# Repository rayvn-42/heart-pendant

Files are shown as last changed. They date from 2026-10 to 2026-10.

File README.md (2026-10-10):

## Heart Pendant
> A two part PCB, one used as a bracelet that senses heart pulses, and a pendant shaped as a heart that shows them

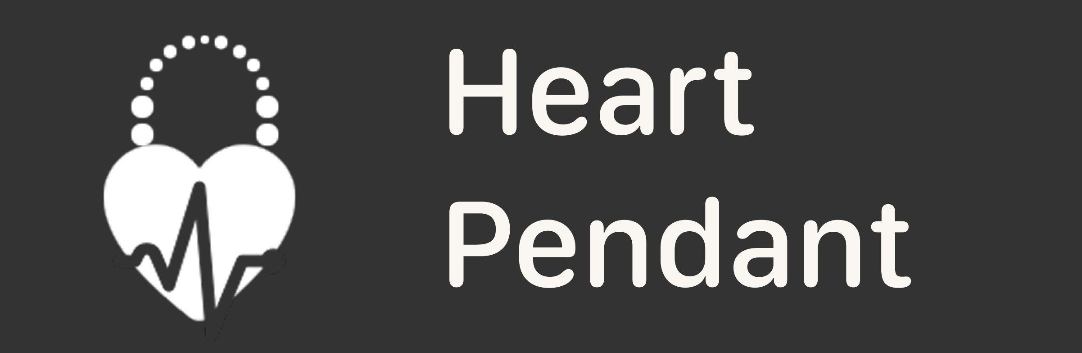
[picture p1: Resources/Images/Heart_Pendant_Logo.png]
Heart Pendant Logo


---

### What is Heart Pendant?
Its a small wearable made of two boards on a single PCB, joined by a break-away joint, The square half is a bracelet that measures the pulse with a heartbeat sensor.The heart-shaped half is a necklace pendant that shows each beat as a light animation moving smoothly around a ring of addressable LEDs. Once you snap the halves apart, each one works on its own and they talk to each other wirelessly.

### Why is Heart Pendant useful?
Its not really useful :), but its just fun and a reminder that each second your heart beats :) or something. I mean its just cool.

---

### How it works?
The bracelet's ESP32-C3 reads a heartbeat sensor module and detects each beat. It sends the beat to the pendant using the ESP-NOW protocol. Then the pendants ESP32 displays that heartbeat as a simple rotational animation using the addressable LEDs. Each half has its own LiPo battery, USB C port with a dedicated charge controller, and a 3v3 regulator, so both can be charged and used separately.

## So far
- [x] Schematic: ESP32 core, USB-C input, charger, regulator, power switch, battery sensing
- [x] Pulse sensor and LED ring
- [x] PCB layout
- [x] Quote Component & PCB + Stencil Order
- [ ] Firmware

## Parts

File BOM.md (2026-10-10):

# Heart pendant – bill of materials

<!-- Generated by Half Life from project cmuuxpitj0bii01smvdh1ma1b. Edits here are overwritten on the next sync. -->
<!-- Generated: 2026-10-10T14:42:43.618Z -->

> [!NOTE]
> This parts list is mirrored from [Half Life](https://halflife.hackclub.com). Editing it here will not change the platform's copy, and the next sync overwrites this file.

| Week | Tier | Parts funding |
| --- | --- | --- |
| Week 1 | Tier 3 | $100.00 |

| Part | What it's for | Qty | Unit | Total | Vendor |
| --- | --- | --- | --- | --- | --- |
| [PCB Components](https://www.lcsc.com/product-detail/C41349510.html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) | All components for the pcb, not indivdually listed since part value too low | 1 | $21.29 | $21.29 | [LCSC](https://www.lcsc.com/product-detail/C41349510.html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) |
| [PCB + Stencil](https://cart.jlcpcb.com/shopcart/cart) | The Board and Stencil | 1 | $16.72 | $16.72 | [JLCPCB](https://cart.jlcpcb.com/shopcart/cart) |
| **Parts subtotal** | — | — | — | **$38.01** | — |
| **Tax & shipping** | — | — | — | **$59.00** | — |
| **Total** | — | — | — | **$97.01** | — |

$2.99 left of the tier's funding.

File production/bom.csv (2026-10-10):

Designator | Footprint | Quantity | Value | LCSC Part #
C1, C24, C28, C7, C8, C9 | 0603 | 6 | 1uF | C1592
C10, C2 | 0805 | 2 | 10uF | C1713
C11, C12, C14, C3, C4, C6 | 0603 | 6 | 4.7uF | C1705
C13, C15, C16, C17, C18, C19, C20, C21, C22, C23, C25, C26, C27, C5 | 0603 | 14 | 100nF | C1590
D1, D2 | 0603 | 2 | LED | C2286
D10, D11, D12, D13, D14, D3, D4, D5, D6, D7, D8, D9 | LED_SK6812MINI-E_3.2x2.8mm_P1.5mm_ReverseMount | 12 | SK6812MINI-E | C5149201
J2, J4 | USB_C_Receptacle_HRO_TYPE-C-31-M-12 | 2 | USB_C_Receptacle_USB2.0_16P | C165948
Q1 | SOT-23 | 1 | 2N7002 | C8545
Q2 | SOT-23 | 1 | AO3401A | C478608
R1, R10, R11, R18, R2 | 0603 | 5 | 100k | C14675
R12, R13, R14, R15, R17, R3, R4, R5, R6 | 0603 | 9 | 10k | C15401
R16, R7 | 0603 | 2 | 470R | C23179
R19 | 0603 | 1 | 330R | C22104
R20, R21, R8, R9 | 0603 | 4 | 5.1k | C14677
SW1, SW3 | SW-SMD_4P-L4.2-W3.4-P2.15-LS5.2 | 2 | SW_Boot | C55200589
SW2, SW4 | SW-TH_MSK12C02 | 2 | SW_SPDT | C431540
U1, U6 | SOT-23-5 | 2 | MCP73831-2-OT | C14879
U2, U7 | WIFIM-SMD_ESP32-C3-MINI-1 | 2 | ESP32-C3-MINI-1-N4X | C41349510
U4, U9 | SOT-23-5 | 2 | AP2112K-3.3 | C51118
U5, U8 | SOT-23-6 | 2 | USBLC6-2SC6 | C7519

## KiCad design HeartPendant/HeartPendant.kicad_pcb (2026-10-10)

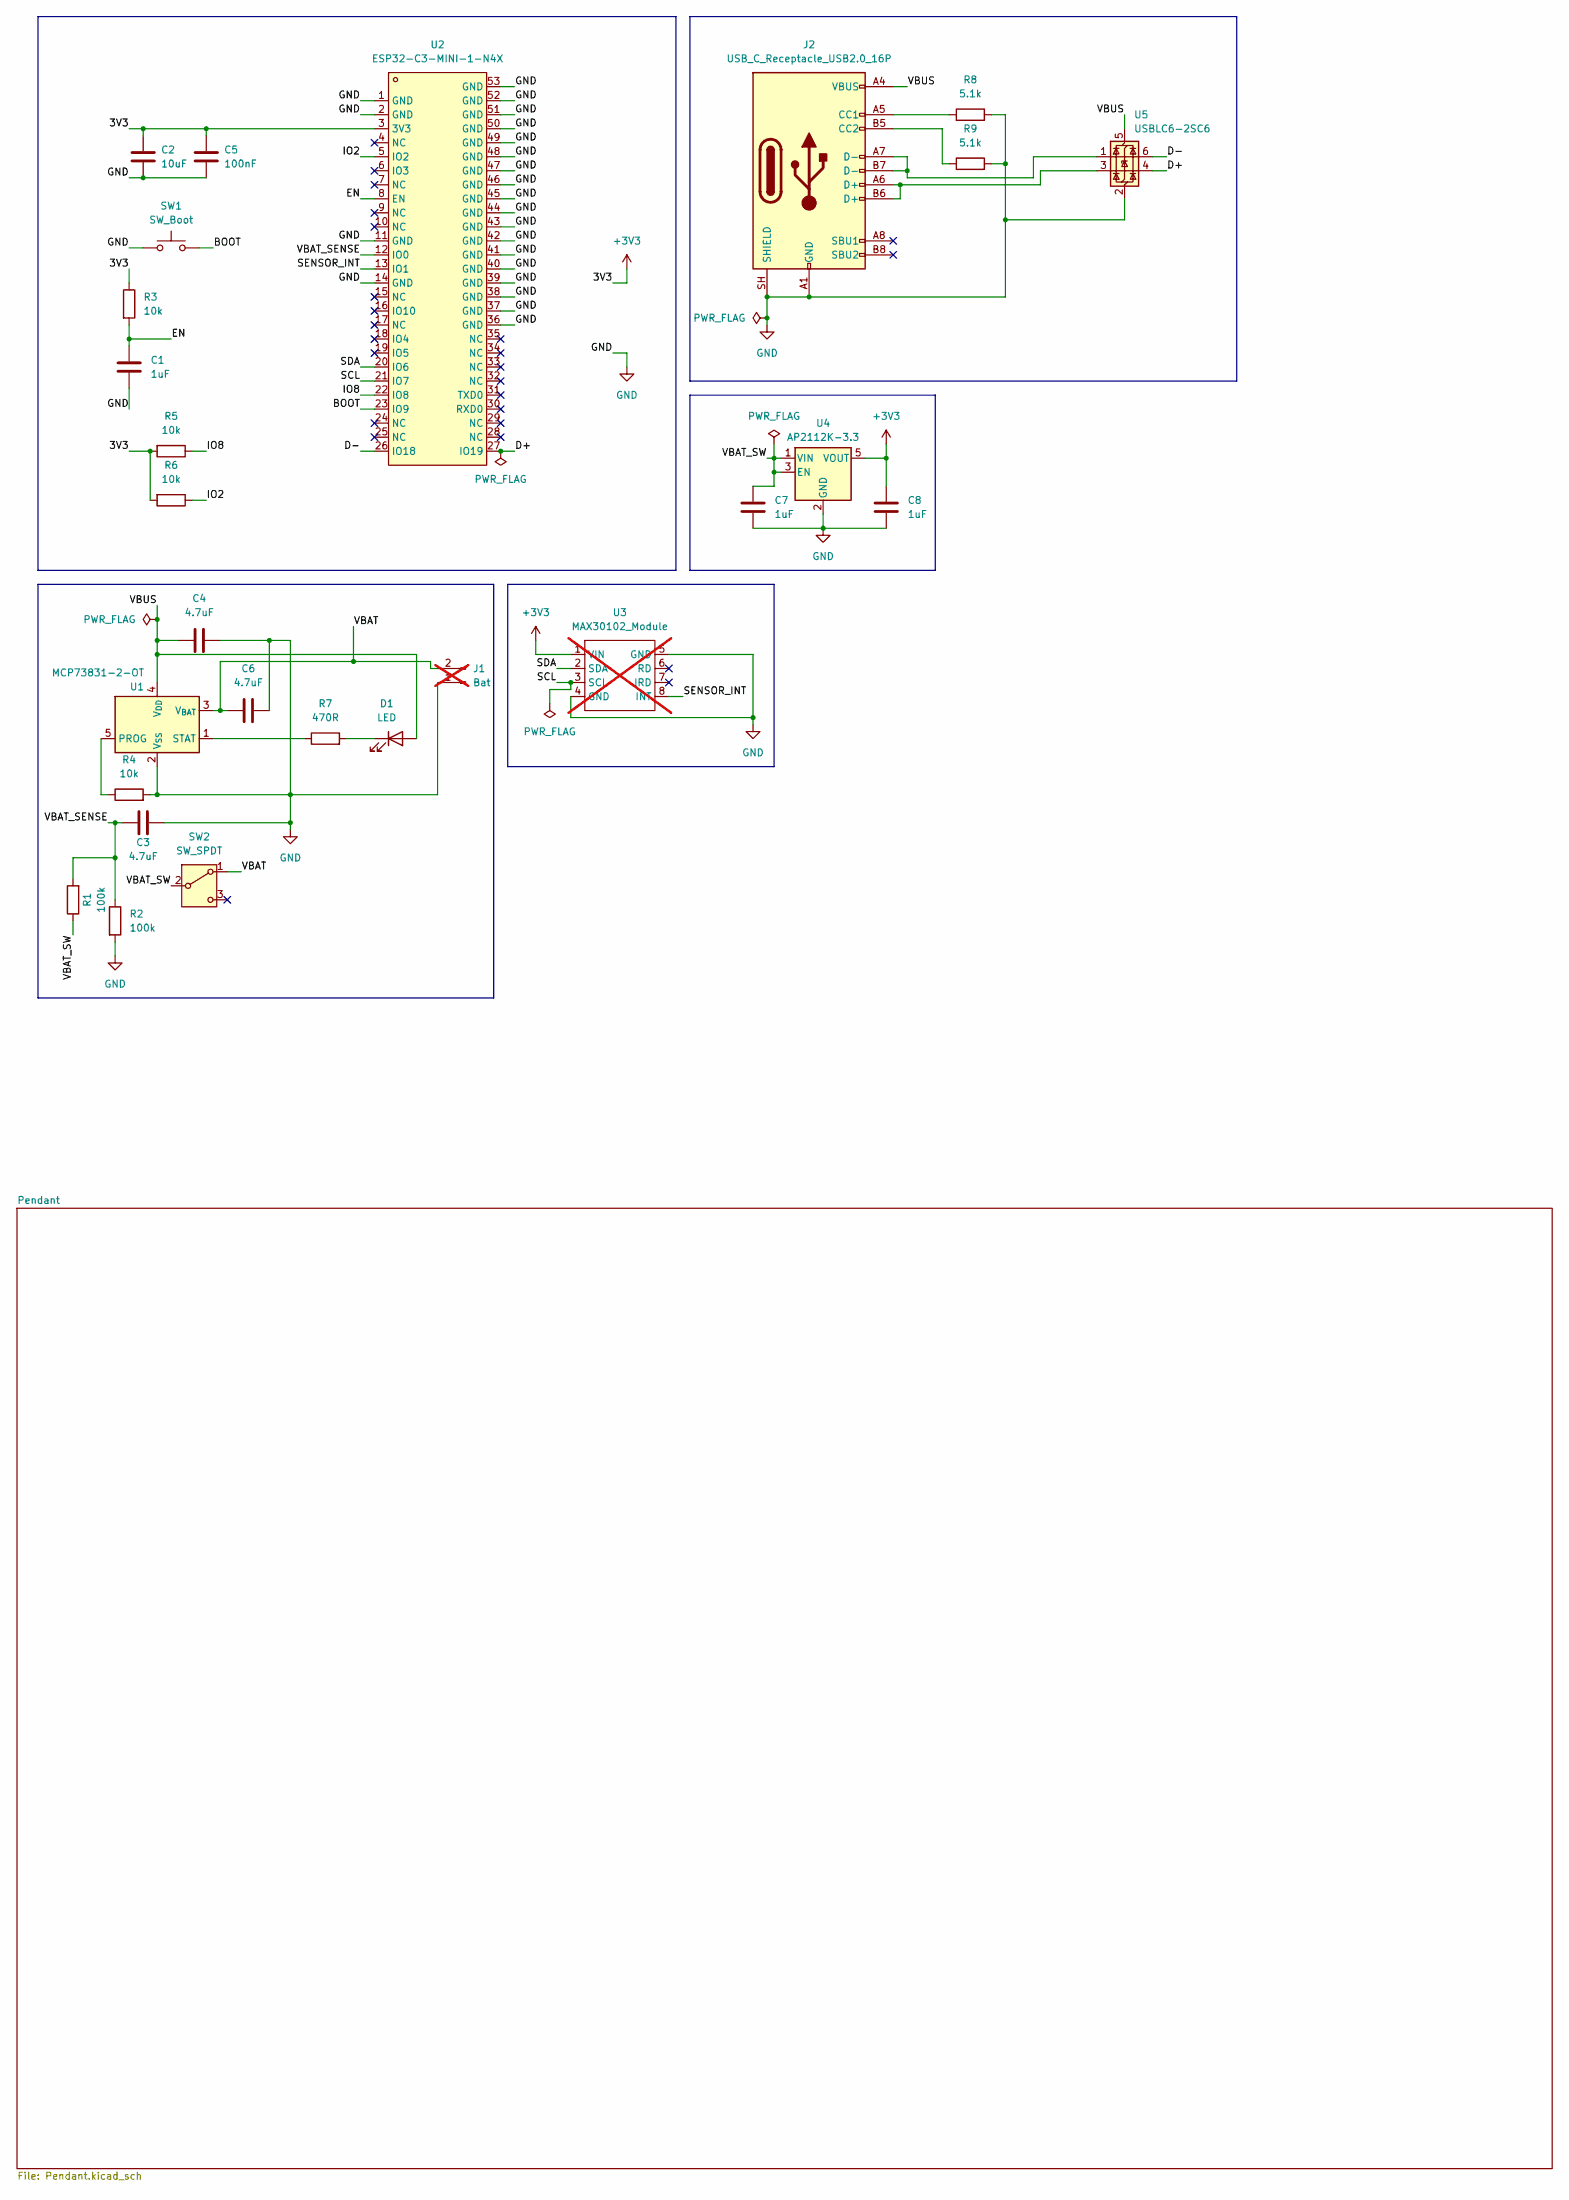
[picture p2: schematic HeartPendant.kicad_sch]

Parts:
C1, C7, C8: 1uF; C_0603_1608Metric; LCSC Part C1592
C2: 10uF; C_0805_2012Metric; LCSC Part C1713
C3, C4, C6: 4.7uF; C_0603_1608Metric; LCSC Part C1705
C5: 100nF; C_0603_1608Metric; LCSC Part C1590
D1: LED; LED_0603_1608Metric; LCSC Part C2286
J1: Bat; PinHeader_1x02_P2.54mm_Vertical; not fitted
J2: USB_C_Receptacle_USB2.0_16P; USB_C_Receptacle_HRO_TYPE-C-31-M-12; LCSC Part C165948
R1, R2: 100k; R_0603_1608Metric; LCSC Part C14675
R3, R4, R5, R6: 10k; R_0603_1608Metric; LCSC Part C15401
R7: 470R; R_0603_1608Metric; LCSC Part C23179
R8, R9: 5.1k; R_0603_1608Metric; LCSC Part C14677
SW1: SW_Boot; SW-SMD_4P-L4.2-W3.4-P2.15-LS5.2; LCSC Part C55200589
SW2: SW_SPDT; SW-TH_MSK12C02; LCSC Part C431540
U1: MCP73831-2-OT; SOT-23-5; LCSC Part C14879
U2: ESP32-C3-MINI-1-N4X; WIFIM-SMD_ESP32-C3-MINI-1; MPN ESP32-C3-MINI-1-N4X; LCSC Part C41349510
U3: MAX30102_Module; Max30102_Module; not fitted
U4: AP2112K-3.3; SOT-23-5; LCSC Part C51118
U5: USBLC6-2SC6; SOT-23-6; LCSC Part C7519

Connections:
+3V3: C2.2, C5.2, C8.1, R3.1, R5.2, R6.2, U2.3 (3V3), U3.1 (VIN), U4.5 (VOUT)
/BOOT: SW1.2, U2.23 (IO9)
/D+: U2.27 (IO19), U5.4 (I/O2)
/D-: U2.26 (IO18), U5.6 (I/O1)
/EN: C1.1, R3.2, U2.8 (EN)
/IO2: R6.1, U2.5 (IO2)
/IO8: R5.1, U2.22 (IO8)
/SCL: U2.21 (IO7), U3.3 (SCL)
/SDA: U2.20 (IO6), U3.2 (SDA)
/SENSOR_INT: U2.13 (IO1), U3.8 (INT)
/VBAT: C6.1, J1.2, SW2.1 (A), U1.3 (V_{BAT})
/VBAT_SENSE: C3.1, R1.2, R2.1, U2.12 (IO0)
/VBAT_SW: C7.1, R1.1, SW2.2 (B), U4.1 (VIN), U4.3 (EN)
/VBUS: C4.1, D1.2 (A), J2.A4 (VBUS), J2.A9 (VBUS), J2.B4 (VBUS), J2.B9 (VBUS), U1.4 (V_{DD}), U5.5 (VBUS)
GND: C1.2, C2.1, C3.2, C4.2, C5.1, C6.2, C7.2, C8.2, J1.1, J2.A1 (GND), J2.A12 (GND), J2.B1 (GND), J2.B12 (GND), J2.SH (SHIELD), R2.2, R4.2, R8.2, R9.2, SW1.1, U1.2 (V_{SS}), U2.1 (GND), U2.2 (GND), U2.11 (GND), U2.14 (GND), U2.36 (GND), U2.37 (GND), U2.38 (GND), U2.39 (GND), U2.40 (GND), U2.41 (GND), U2.42 (GND), U2.43 (GND), U2.44 (GND), U2.45 (GND), U2.46 (GND), U2.47 (GND), U2.48 (GND), U2.49 (GND), U2.50 (GND), U2.51 (GND), U2.52 (GND), U2.53 (GND), U3.4 (GND), U3.5 (GND), U4.2 (GND), U5.2 (GND)
unnamed: D1.1 (K), R7.2
unnamed: J2.A5 (CC1), R8.1
unnamed: J2.B5 (CC2), R9.1
unnamed: J2.A6 (D+), J2.B6 (D+), U5.3 (I/O2)
unnamed: J2.A7 (D-), J2.B7 (D-), U5.1 (I/O1)
unnamed: R4.1, U1.5 (PROG)
unnamed: R7.1, U1.1 (STAT)

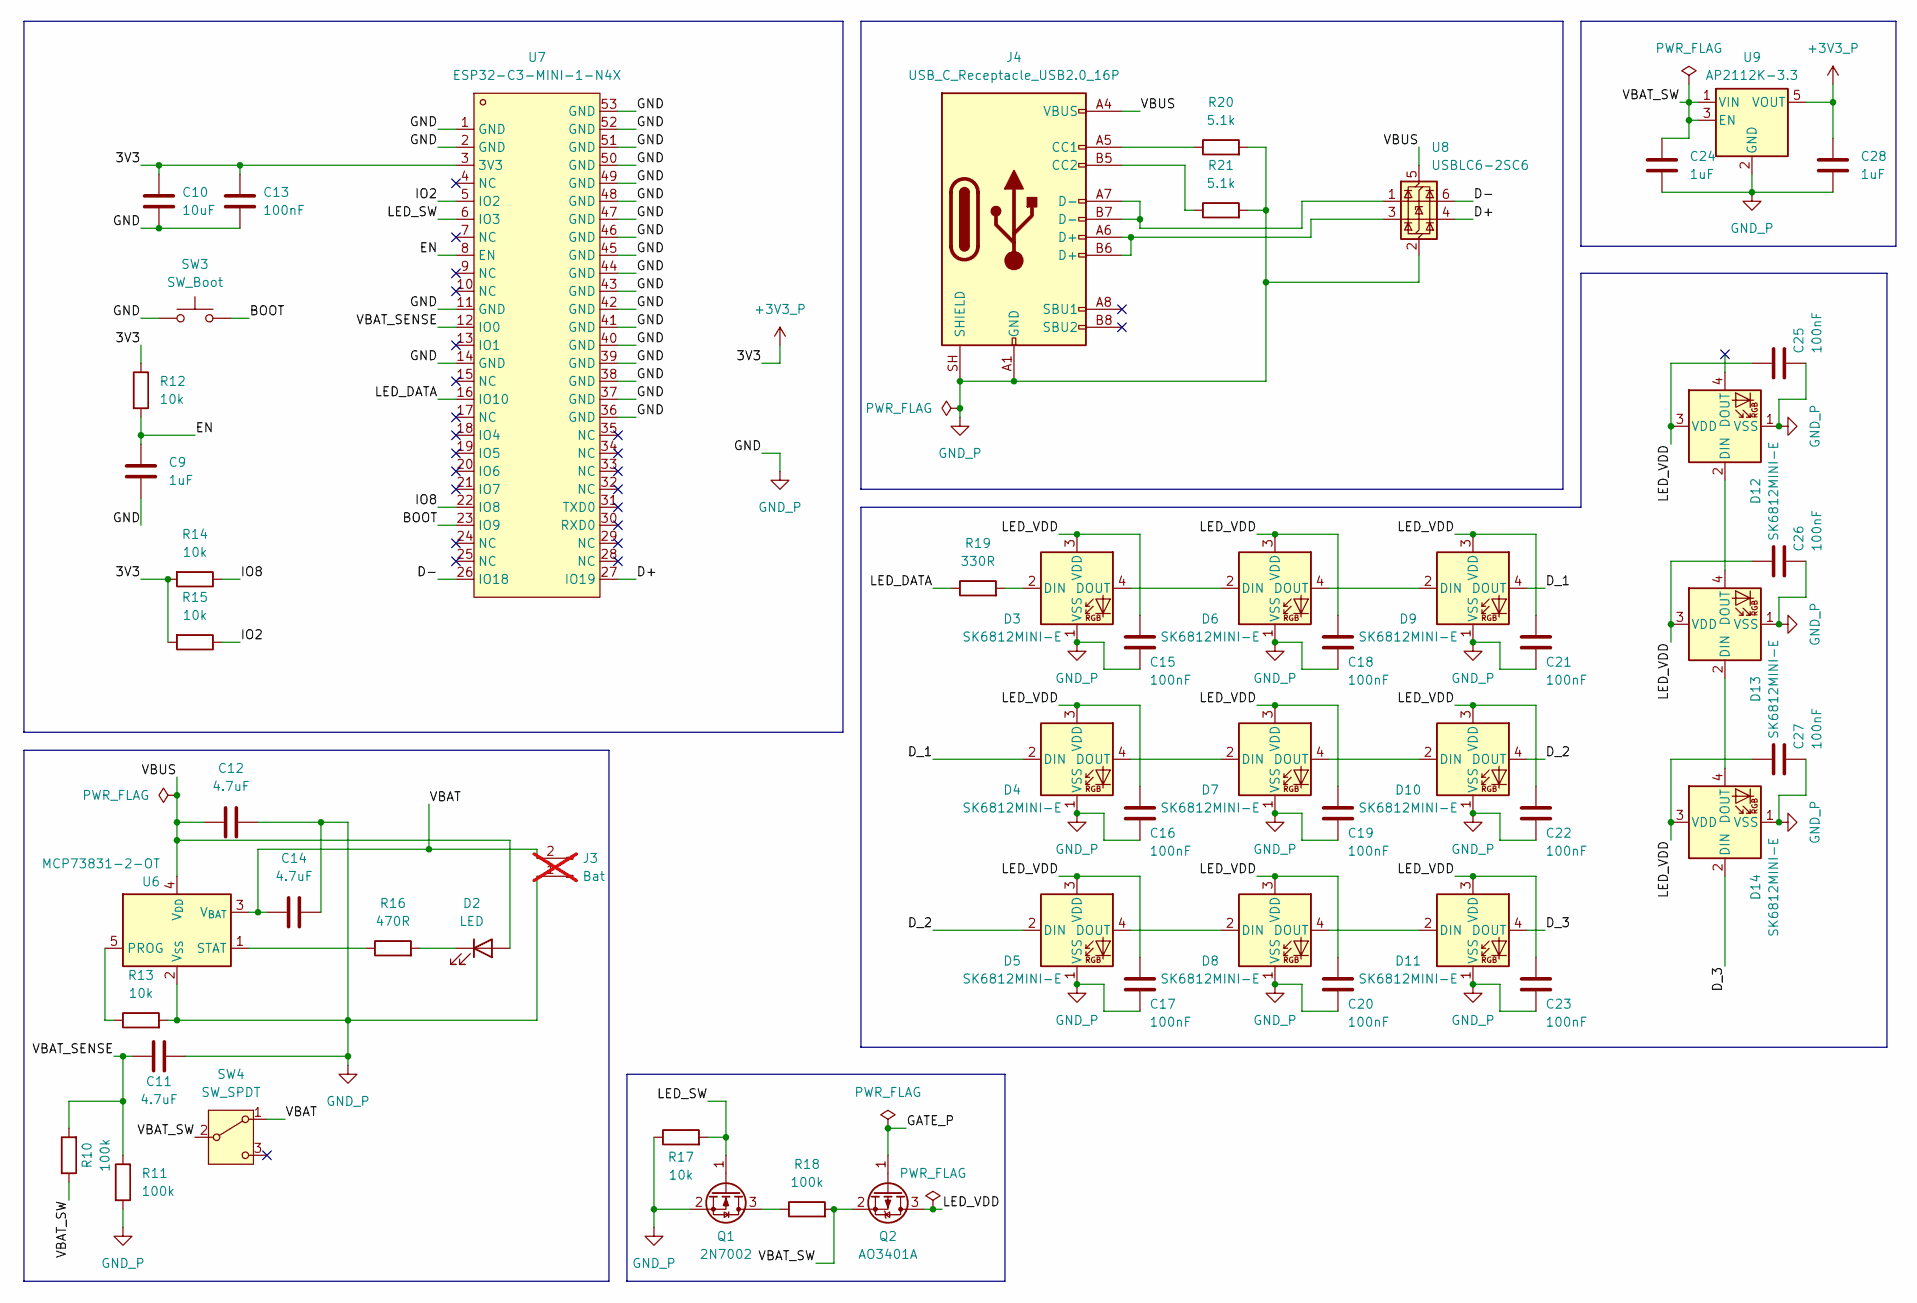
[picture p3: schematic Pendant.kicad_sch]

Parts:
C9, C24, C28: 1uF; C_0603_1608Metric; LCSC Part C1592
C10: 10uF; C_0805_2012Metric; LCSC Part C1713
C11, C12, C14: 4.7uF; C_0603_1608Metric; LCSC Part C1705
C13, C15, C16, C17, C18, C19, C20, C21, C22, C23, C25, C26, C27: 100nF; C_0603_1608Metric; LCSC Part C1590
D2: LED; LED_0603_1608Metric; LCSC Part C2286
D3, D4, D5, D6, D7, D8, D9, D10, D11, D12, D13, D14: SK6812MINI-E; LED_SK6812MINI-E_3.2x2.8mm_P1.5mm_ReverseMount; LCSC Part C5149201
J3: Bat; PinHeader_1x02_P2.54mm_Vertical; not fitted
J4: USB_C_Receptacle_USB2.0_16P; USB_C_Receptacle_HRO_TYPE-C-31-M-12; LCSC Part C165948
Q1: 2N7002; SOT-23; LCSC Part C8545
Q2: AO3401A; SOT-23; LCSC Part C478608
R10, R11, R18: 100k; R_0603_1608Metric; LCSC Part C14675
R12, R13, R14, R15, R17: 10k; R_0603_1608Metric; LCSC Part C15401
R16: 470R; R_0603_1608Metric; LCSC Part C23179
R19: 330R; R_0603_1608Metric; LCSC Part C22104
R20, R21: 5.1k; R_0603_1608Metric; LCSC Part C14677
SW3: SW_Boot; SW-SMD_4P-L4.2-W3.4-P2.15-LS5.2; LCSC Part C55200589
SW4: SW_SPDT; SW-TH_MSK12C02; LCSC Part C431540
U6: MCP73831-2-OT; SOT-23-5; LCSC Part C14879
U7: ESP32-C3-MINI-1-N4X; WIFIM-SMD_ESP32-C3-MINI-1; MPN ESP32-C3-MINI-1-N4X; LCSC Part C41349510
U8: USBLC6-2SC6; SOT-23-6; LCSC Part C7519
U9: AP2112K-3.3; SOT-23-5; LCSC Part C51118

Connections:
+3V3_P: C10.2, C13.2, C28.1, R12.1, R14.2, R15.2, U7.3 (3V3), U9.5 (VOUT)
/Pendant/BOOT: SW3.2, U7.23 (IO9)
/Pendant/D+: U7.27 (IO19), U8.4 (I/O2)
/Pendant/D-: U7.26 (IO18), U8.6 (I/O1)
/Pendant/D_1: D4.2 (DIN), D9.4 (DOUT)
/Pendant/D_2: D5.2 (DIN), D10.4 (DOUT)
/Pendant/D_3: D11.4 (DOUT), D14.2 (DIN)
/Pendant/EN: C9.1, R12.2, U7.8 (EN)
/Pendant/GATE_P: Q2.1 (G)
/Pendant/IO2: R15.1, U7.5 (IO2)
/Pendant/IO8: R14.1, U7.22 (IO8)
/Pendant/LED_DATA: R19.1, U7.16 (IO10)
/Pendant/LED_SW: Q1.1 (G), R17.2, U7.6 (IO3)
/Pendant/LED_VDD: C15.1, C16.1, C17.1, C18.1, C19.1, C20.1, C21.1, C22.1, C23.1, C25.1, C26.1, C27.1, D3.3 (VDD), D4.3 (VDD), D5.3 (VDD), D6.3 (VDD), D7.3 (VDD), D8.3 (VDD), D9.3 (VDD), D10.3 (VDD), D11.3 (VDD), D12.3 (VDD), D13.3 (VDD), D14.3 (VDD), Q2.3 (D)
/Pendant/VBAT: C14.1, J3.2, SW4.1 (A), U6.3 (V_{BAT})
/Pendant/VBAT_SENSE: C11.1, R10.2, R11.1, U7.12 (IO0)
/Pendant/VBAT_SW: C24.1, Q2.2 (S), R10.1, R18.2, SW4.2 (B), U9.1 (VIN), U9.3 (EN)
/Pendant/VBUS: C12.1, D2.2 (A), J4.A4 (VBUS), J4.A9 (VBUS), J4.B4 (VBUS), J4.B9 (VBUS), U6.4 (V_{DD}), U8.5 (VBUS)
GND_P: C9.2, C10.1, C11.2, C12.2, C13.1, C14.2, C15.2, C16.2, C17.2, C18.2, C19.2, C20.2, C21.2, C22.2, C23.2, C24.2, C25.2, C26.2, C27.2, C28.2, D3.1 (VSS), D4.1 (VSS), D5.1 (VSS), D6.1 (VSS), D7.1 (VSS), D8.1 (VSS), D9.1 (VSS), D10.1 (VSS), D11.1 (VSS), D12.1 (VSS), D13.1 (VSS), D14.1 (VSS), J3.1, J4.A1 (GND), J4.A12 (GND), J4.B1 (GND), J4.B12 (GND), J4.SH (SHIELD), Q1.2 (S), R11.2, R13.2, R17.1, R20.2, R21.2, SW3.1, U6.2 (V_{SS}), U7.1 (GND), U7.2 (GND), U7.11 (GND), U7.14 (GND), U7.36 (GND), U7.37 (GND), U7.38 (GND), U7.39 (GND), U7.40 (GND), U7.41 (GND), U7.42 (GND), U7.43 (GND), U7.44 (GND), U7.45 (GND), U7.46 (GND), U7.47 (GND), U7.48 (GND), U7.49 (GND), U7.50 (GND), U7.51 (GND), U7.52 (GND), U7.53 (GND), U8.2 (GND), U9.2 (GND)
unnamed: D2.1 (K), R16.2
unnamed: D3.2 (DIN), R19.2
unnamed: D3.4 (DOUT), D6.2 (DIN)
unnamed: D4.4 (DOUT), D7.2 (DIN)
unnamed: D5.4 (DOUT), D8.2 (DIN)
unnamed: D6.4 (DOUT), D9.2 (DIN)
unnamed: D7.4 (DOUT), D10.2 (DIN)
unnamed: D8.4 (DOUT), D11.2 (DIN)
unnamed: D12.2 (DIN), D13.4 (DOUT)
unnamed: D13.2 (DIN), D14.4 (DOUT)
unnamed: J4.A5 (CC1), R20.1
unnamed: J4.B5 (CC2), R21.1
unnamed: J4.A6 (D+), J4.B6 (D+), U8.3 (I/O2)
unnamed: J4.A7 (D-), J4.B7 (D-), U8.1 (I/O1)
unnamed: Q1.3 (D), R18.1
unnamed: R13.1, U6.5 (PROG)
unnamed: R16.1, U6.1 (STAT)

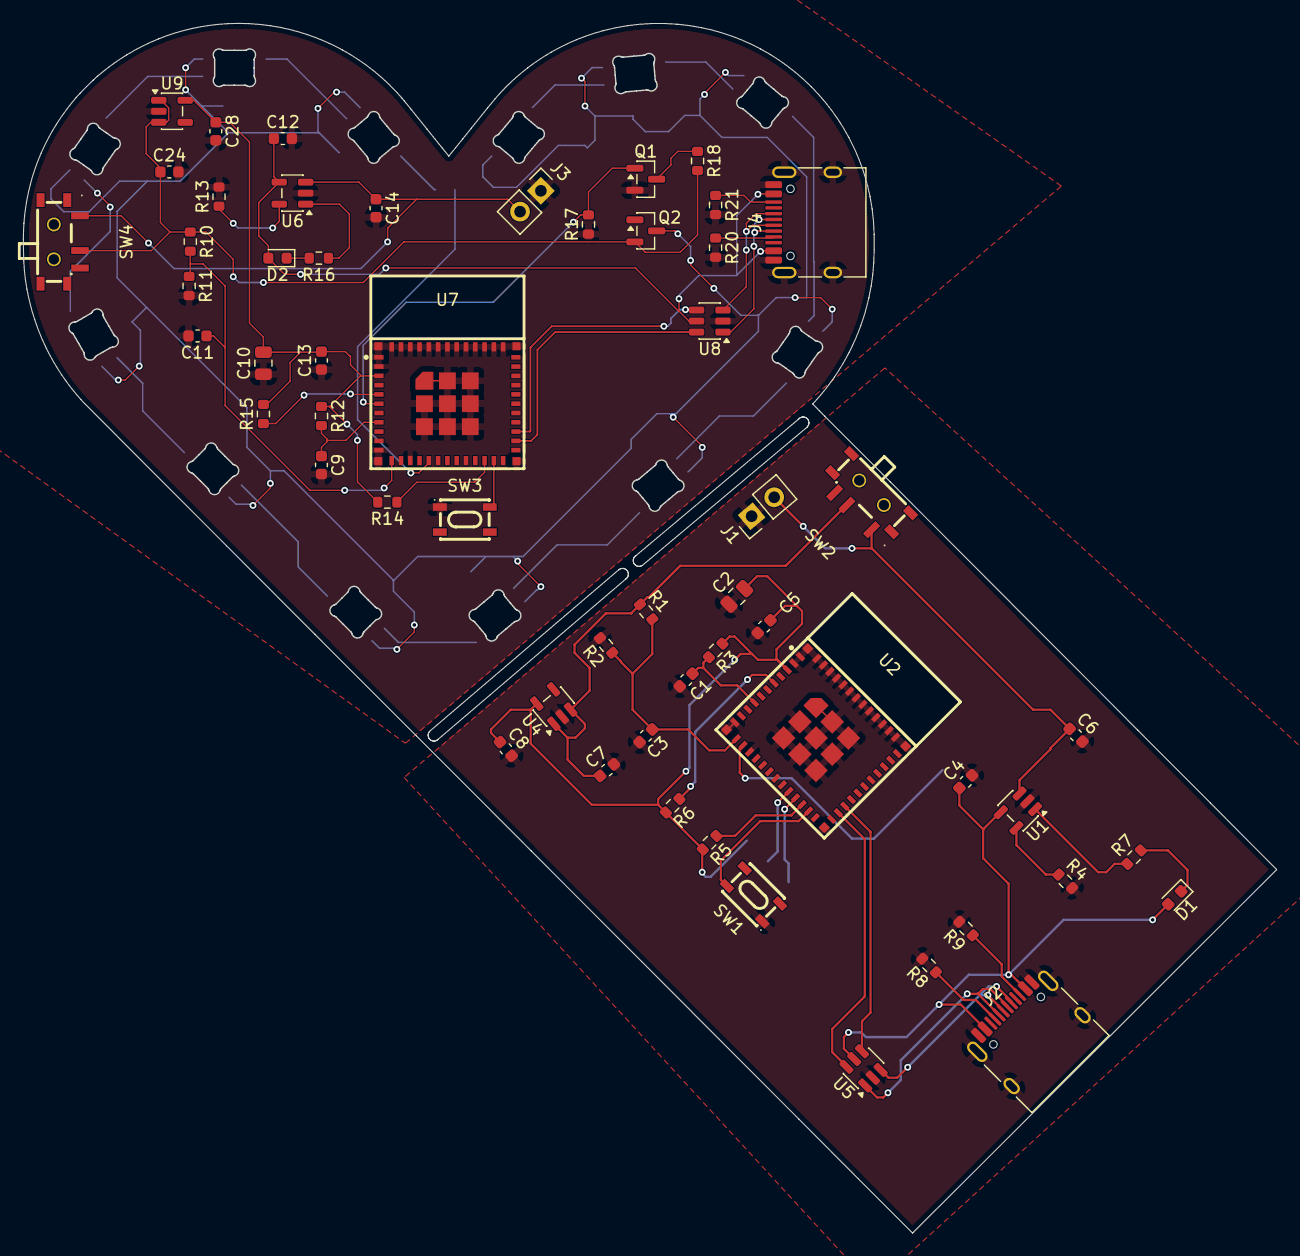
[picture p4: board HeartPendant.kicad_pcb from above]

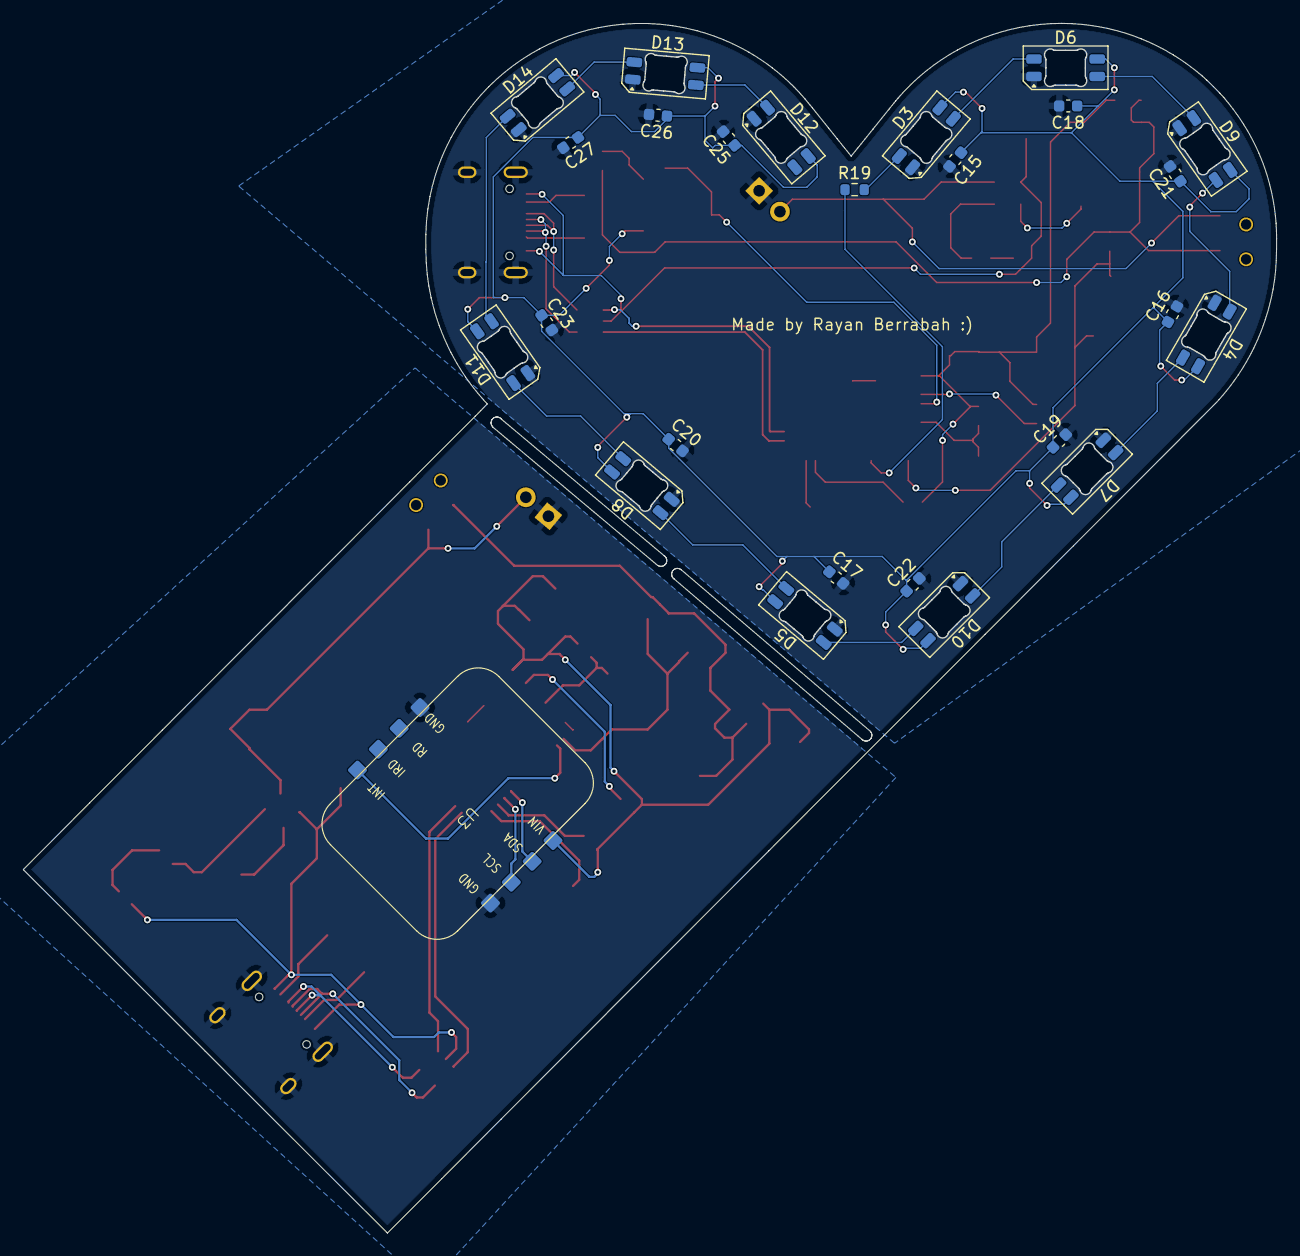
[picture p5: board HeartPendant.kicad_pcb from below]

Board: 2 copper layers, 108.0 x 104.2 mm, 82 parts (26 on the bottom side), 57 nets.

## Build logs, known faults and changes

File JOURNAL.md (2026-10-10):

# Heart pendant – devlog

<!-- Generated by Half Life from project cmuuxpitj0bii01smvdh1ma1b. Edits here are overwritten on the next sync. -->
<!-- Generated: 2026-10-10T15:42:48.706Z -->

> [!NOTE]
> This devlog is mirrored from [Half Life](https://halflife.hackclub.com). Editing it here will not change the platform's copy, and the next sync overwrites this file.

> A small two part PCB with break away joints. On as a bracelet which measures heartbeats and one as a necklace which shows those heartbeats through a array of addressable LEDs.

| Week | Tier | Hours logged | Entries |
| --- | --- | --- | --- |
| Week 1 | Tier 3 | 32.6h | 4 |

## Contents

1. [2026-10-06 – ## First entry, but I did do a looot!!](#2026-10-06-first-entry-but-i-did-do-a-looot)
2. [2026-10-07 – ## Finished the bracelet, and started on Pendant :)](#2026-10-07-finished-the-bracelet-and-started-on-pendant)
3. [2026-10-08 – ## I actually locked in today](#2026-10-08-i-actually-locked-in-today)
4. [2026-10-10 – ## I am finally done!!!!](#2026-10-10-i-am-finally-done)

## Design

### 2026-10-06 – ## First entry, but I did do a looot!!

**5h**

## First entry, but I did do a looot!!
> TL;DR: Got the idea, defined the components, and started on the MCU and power modules.
---
So first things first was to find an idea on what to make, after a while of thinking and researching, I decided to make a two piece PCB, where on half get hung on a persons neck as a pendant, and one as a bracelet that goes around the wrist. The pendant half has addressable LEDs, which show the persons heartbeat, its also rechargeable via an internal battery and a USB C port. The bracelet half has a pulse sensor, some status LEDs, and also an internal battery with a USB C port. The port is also used to initially program the ESP32-C3-MINI-1-H4X's, which communicate with each other via the ESP-NOW protocol. The PCB(s) also have a 3v3 voltage regulator (AP2112K-3.3), a USB esd protection (USBLC6-2SC6), and a LiPo charge controller (MCP73831). And to obviously know how to connect everything, I had to look through each of the ICs typical application diagrams.









To be honest I forgot to take screenshot when I was making it, but I did run into some issues with the ERC (Electric Rules Check) which was complaining about power pins not having sources, but I found out that it could actually be easily fixed using PWR_FLAG. But that was it so far, here's the current schematic:

output_page-0001

That's it so far, for tomorrow I'll probably work on the actual pulse sensor, and format everything better.

### 2026-10-07 – ## Finished the bracelet, and started on Pendant :)

**9h**

## Finished the bracelet, and started on Pendant :)
> TL;DR: Finished working on the bracelet by adding the pulse sensor as a custom symbol, And started on the Pendant, Added LEDs.
---
First, I ran the ERC to make sure everything was working, had some warnings but nothing major, then I looked for the pulse sensor that I was going to use, and found an I2C breakout board that could soldered on top of the bracelet PCB.

MAX30102-Module-Capteur-dOxygene-et-rythme-cardiaque-agadir-scaled

Once I got that sorted, I searched if there was a pre-made symbol & footprint already made, and I couldn't find anything for the module I decided to use, So I had to make a custom one, which isn't hard. I only made the symbol (for now) but I will add the footprint later.



Then I looked for a youtube video of how it usually wired, and used that to make the schematic for mine.



After that was done, basically the bracelet schematic half was done. Next I added a new sheet for the pendant. And I basically just copied the MCU, USB C, and power management parts of the bracelet over.



Next I picked the addressable led modules that I was going to use, I first considered using a seperate module, but then later setteled on just getting the raw led, after searching, I found SK6812 MINI-E, which are RBG Addressable LEDs, which is perfect, it even allowed me to show different colors when for example the pendant is charging and stuff.



Then I had to add a mosfet transistor because even when the LEDs are off, they still consume energy which will drain the battery, I found a design and just to be honest copied it. It uses two transistors, which basically make sure the full voltage goes through. I used 2N7002 and A03401A.





Then I first started by implementing the two part power management part.



Then added the LEDs, also adding a current limiting resistor and 100nF capacitors from the LED voltage to ground. And that was it.



### 2026-10-08 – ## I actually locked in today

**11h**

## I actually locked in today
> 11 hours of continious tedious pcb designing.
---
So first I started by designing a custom footprint for the MAX30102 module that I was gonna use.



Then I took those measurements and also found the pin spacing which was standard 2.54 mm. Suprisingly, a Aliexpress listing for the exact same module was what helped me actually figure all this out.



Then I started working on it on KiCad. It was pretty easy, and I decided to solder the module as a SMD component, because it has side pins that were compatible with SMD. I added the pins and some text for each pin.



After that was done, I assigned the footprint to the symbol, and switched to PCB mode, and update the PCB from schematic which basically transfered all the components over to the PCB mode.



Once that was done, I started by grouping each component close to where it needed to be. And separating the Pendant and Bracelet sides.



And also started grouping and formating the Pendant too, It was a little bit difficult but still doable.



Then I had to design the actual board layout so that I can figure out where each component goes, So I just used Figma to design the board shape, export it as a SVG, then convert it to DXF which then can be imported into KiCad and used as Edge Cut layer.



Once that was done, I imported it, scaled it, and started laying out the components inside, deciding where each component went, and where the USB C was facing, etc.



Then layed everything out, made sure nothing was intersecting.



Then next was the Bracelet half, did the same thing.



Next was adding the ground plan fill in, which was easy, they had to be seperate for each side, I also added keep-out areas where the ESP32 antennas were (I forgot the Pendant half, but I will fix it tomorrow).



Next came the routing, I decided to only do the Bracelet half for this day, and leave the other half for tomorrow, I was somewhat confusing at first, but I got it done (even tho to be honest it looks shii :) ).



Next things are probably route the Pendant half, BOM, drill files , gerber, Pick and Place (for the assembly), get the JLCPCB quote, and finally the actual code.

### 2026-10-10 – ## I am finally done!!!!

**7.6h**

## I am finally done!!!!
> TL;DR: Finished PCB, quoted parts and PCB + Stencil. Coded the firmware.
---
Finally finished the PCB design, ran DRC, fixed all errors and some warnings. And looked at the 3D preview





Then I got to generating the Gerbers and stuff. I first was gonna use the built-in gerber and drill file generator.



But then I found that there was a plugin that basically generated all the files needed for JLCPCB fabrication. But I first had to assign each component, its respective LCSC Part number for the BOM, I left out and marked the MAX30102 Module as DNP because I sourced it locally. So I found each component with the correct package type.







Then generated all the files



I actually was first going to get everything already assembled from JLCPCB but that was way too expensive :(





Once everything was quoted (came just under 100$), I started working on the firmware, I used Adafruit's NeoPixel library for the LEDs and SparkFun's MAX3010x library for the pulse sensor, then looked at example code for each, and made a example code for each half, not the final version just an example.





AND WITH THATAAT I WAS DONEEEEEE!!!!!! finally :)

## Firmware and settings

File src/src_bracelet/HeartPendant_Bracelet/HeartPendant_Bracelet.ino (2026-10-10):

#include <Wire.h>
#include "MAX30105.h"

MAX30105 sensor;

#define I2C_SDA 6
#define I2C_SCL 7

void setup() {
  Serial.begin(115200);
  while (!Serial);

  Serial.println("Intialize MAX30102");
  Wire.begin(I2C_SDA, I2C_SCL, 400000);

  if (!sensor.begin(Wire, I2C_SPEED_FAST)) {
    Serial.println("MAX30102 not found.");
    while (1);
  }

  sensor.setup();
}

void loop() {
  long irValue = particleSensor.getIR();
  long redValue = particleSensor.getRed();

  if (irValue < 50000) {
    Serial.println("No pulse detected");
  } else {
    Serial.print("IR:");
    Serial.print(irValue);
    Serial.print(",");
    Serial.print("Red:");
    Serial.println(redValue);
  }
  delay(20);
}

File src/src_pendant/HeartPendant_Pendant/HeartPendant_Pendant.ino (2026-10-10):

#include <Adafruit_NeoPixel.h>

#define DATA_PIN 10
#define LED_COUNT 12

Adafruit_NeoPixel strip = Adafruit_NeoPixel(LED_COUNT, DATA_PIN, NEO_GRB + NEO_KHZ800);

void setup() {
  strip.begin();
  strip.show();
  strip.setBrightness(50);
}

void loop() {
  for (int i = 0; i < LED_COUNT; i++) {
    strip.setPixelColor(i, strip.Color(255, 0, 0, 50));
  }
  strip.show();
  delay(1000);

  for (int i = 0; i < LED_COUNT; i++) {
    strip.setPixelColor(i, strip.Color(0, 0, 0, 0));
  }
  strip.show();
  delay(1000);
}

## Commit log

2026-10-06 Initial commit: Added MCU and power management, and README
    [HeartPendant.kicad_pcb, HeartPendant.kicad_sch]
2026-10-07 Added: Added the pulse sensor module
    [HeartPendant.kicad_sch]
2026-10-07 Added: added LED array, and LED power managment
    [HeartPendant.kicad_sch, Pendant.kicad_sch]
2026-10-08 Added: Started on PCB, made custom outline, finished routing Bracelet
    [HeartPendant.kicad_pcb, HeartPendant.kicad_sch, Pendant.kicad_sch]
2026-10-10 Finished pendant routing, added production files
    [HeartPendant.kicad_pcb, HeartPendant.kicad_sch, Pendant.kicad_sch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]
